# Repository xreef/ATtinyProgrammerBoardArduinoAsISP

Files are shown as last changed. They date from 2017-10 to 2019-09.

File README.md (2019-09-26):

### Additional information and document update here on my site: [ATtyny Article](https://www.mischianti.org/2019/08/02/attiny-programmer-board-arduinouno-as-isp/).

# ATtiny programmer board (ArduinoUNO as ISP) #

Video of Attiny board (https://www.youtube.com/watch?v=rCrS0gHoqbE)

### ATtiny13/ATtiny13a/ATtiny25/ATtiny45/ATtiny85 ###
I really like the ATtiny, and for programmaer It, so I build a simple board to use ArduinoUNO as ISP in a faster way.

For Original ArduinoUNO there is a little variant because compatible one have another 5v VCC over RESET pin,  
Arduino uno have IOREF instead.

(In project you can find fritzing file, the simple examples and schema).

## ATtiny13a variant
I buy ATtiny13a very low cost IC (less than 0.5€), with 4 analog pin and 2 PWM/TIMER PIN. 

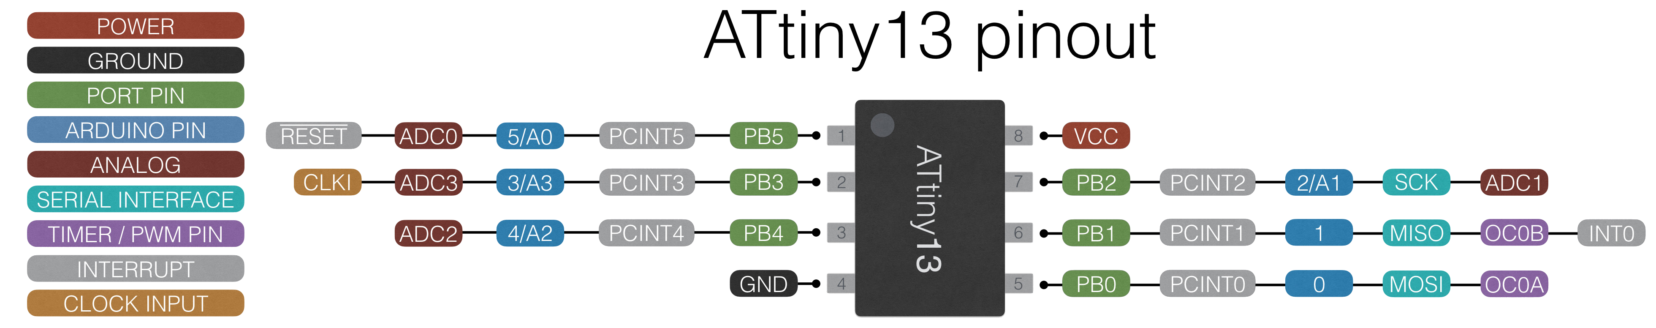
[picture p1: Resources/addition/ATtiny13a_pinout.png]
ATtiny13a pinout


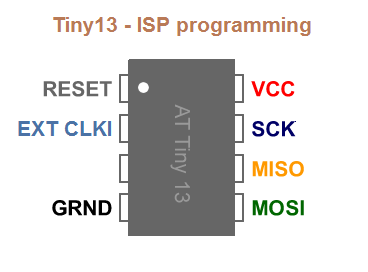
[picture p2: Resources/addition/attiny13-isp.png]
ATtiny13a isp


## How to program an ATtiny:
### Prepare ArduinoUNO to use it as ISP
1. In Arduino IDE select ArduinoUNO board (`Tool --> Board --> ArduinoUNO` - `Strumenti --> Scheda --> ArduinoUNO`);
2. Than open ArduinoISP example file (`File --> Examples/Esempi --> 11.ArduinoISP --> ArduinoISP`);
3. Upload Arduino (`Sketch --> Upload/Carica`);
4. Close IDE.
### Add support for ATtiny:
**ATtiny13/ATtiny13a** ([GitHub ATtiny13 support](https://github.com/MCUdude/MicroCore)):

1. Open the Arduino IDE;
2. Open the `File > Preferences` menu item;
3. Enter the following URL in Additional Boards Manager URLs: [`https://mcudude.github.io/MicroCore/package_MCUdude_MicroCore_index.json`](https://mcudude.github.io/MicroCore/package_MCUdude_MicroCore_index.json) ;
4. Open the `Tools > Board > Boards Manager`... menu item;
5. Wait for the platform indexes to finish downloading;
6. Scroll down until you see the MicroCore entry and click on it;
7. Click Install;
8. After installation is complete close the Boards Manager window.

**ATtiny25/ATtiny45/ATtiny85** ([GitHub other ATtiny support](https://github.com/damellis/attiny/))

1. Open the Arduino IDE;
2. Open the File > Preferences menu item;
3. Enter the following URL in Additional Boards Manager URLs: [`https://raw.githubusercontent.com/damellis/attiny/ide-1.6.x-boards-manager/package_damellis_attiny_index.json`](https://raw.githubusercontent.com/damellis/attiny/ide-1.6.x-boards-manager/package_damellis_attiny_index.json) ;
4. Open the Tools > Board > Boards Manager... menu item;
5. Wait for the platform indexes to finish downloading;
6. Scroll down until you see the MicroCore entry and click on it;
7. Click Install;
8. After installation is complete close the Boards Manager window.

### Upload to ATtiny
1. Attach board to ArduinoUNO;
2. Insert ATtinyXX;
3. If the board is v03 than activate test led otherwise using a breadboard and take VCC from upper right pin of attiny and GND to down left pin, than connect 0 pin (down right) to a led;
4. Select board with correct setting and PORT (`Tools --> Board/Strumenti --> Scheda`);
5. Select Arduino as ISP (`Tools --> Programmer --> Arduino as ISP/Strumenti --> Programmatore --> Arduino as ISP`); 
`note: Arduino as ISP is different from ArduinoISP`.
6. Upload program (`Sketch --> Upload from programmer` / `Schetch --> Carica tramite un programmatore`).
   
### Sample sketch
```cpp
#define PIN 0

void setup()
{
  pinMode(PIN, OUTPUT);
}

void loop()
{
  digitalWrite(PIN, LOW);
  delay(500);
  digitalWrite(PIN, HIGH);
  delay(500);
}

```
   
## Schema:

I use a [prefored board](https://www.aliexpress.com/item/10pcs-lot-3cm-x-7cm-Double-Side-prototype-pcb-3-7-Proto-Board/32685891618.html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,searchweb201602_3_10152_10065_10151_10344_10068_10345_10342_10343_10340_10341_10541_10084_10083_10304_10307_10177_5640015_5590015_10302_10060_10155_10154_10056_10055_10539_10538_5370015_10537_10312_10536_10059_10313_10184_10314_10534_10533_100031_10103_10073_10102_10142_10107,searchweb201603_30,ppcSwitch_2&btsid=0fc181c5-3d4e-4580-bf8d-0318e539854f&algo_expid=0158e307-1a76-404c-8a83-54b0cd5e7954-0&algo_pvid=0158e307-1a76-404c-8a83-54b0cd5e7954), and to switch Voltage and to enable test led I use a smd on/off button instead pin with jumper.

The board is double side so I can attach pin and componend up and down the board. 

Board v01:

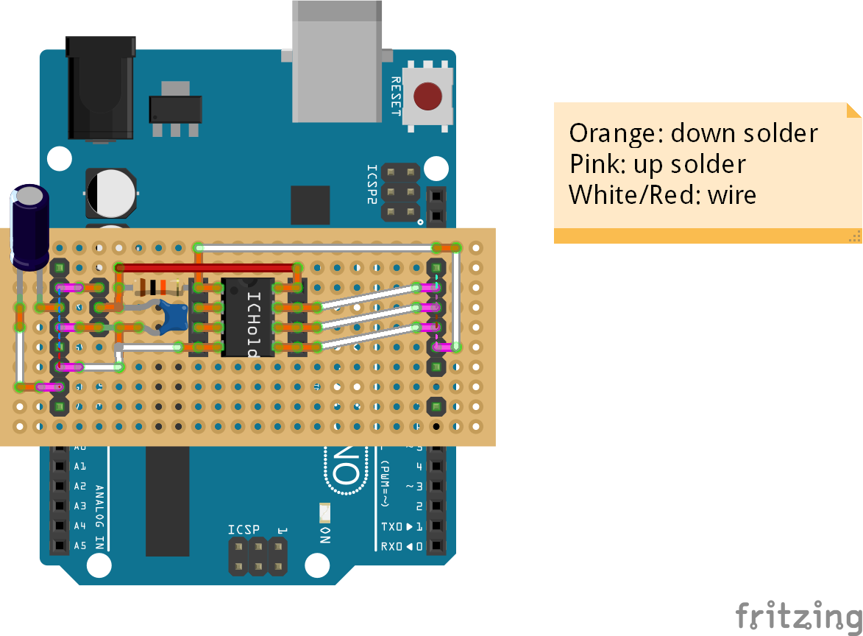
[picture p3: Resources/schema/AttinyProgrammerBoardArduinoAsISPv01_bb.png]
board v01


Board v01 (Original ArduinoUNO):

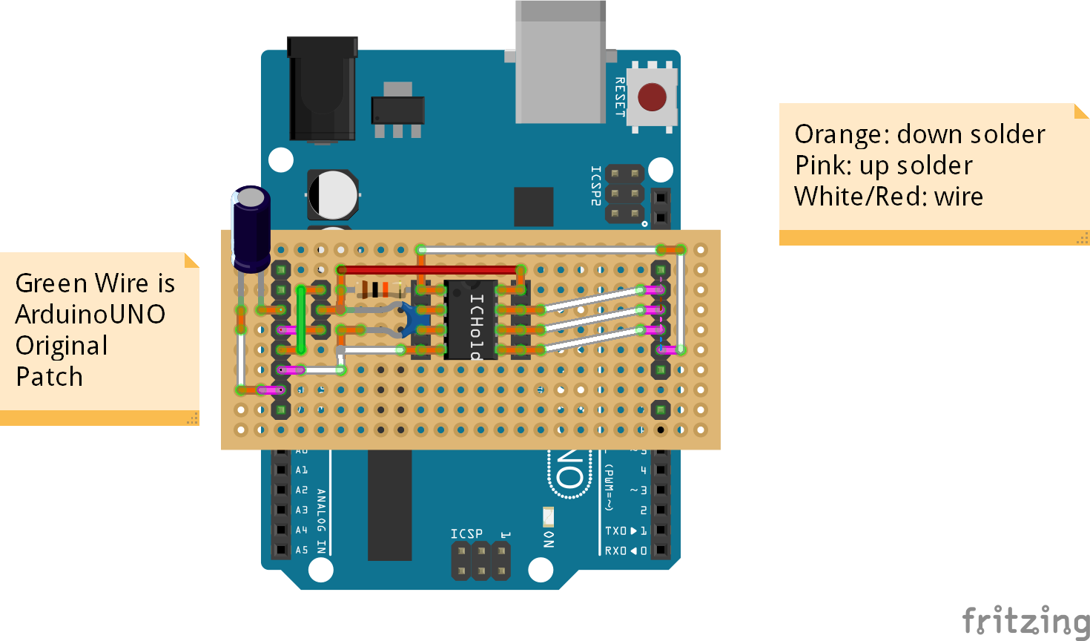
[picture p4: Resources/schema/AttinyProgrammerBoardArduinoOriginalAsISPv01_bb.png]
board v01


Board v02 (power led):

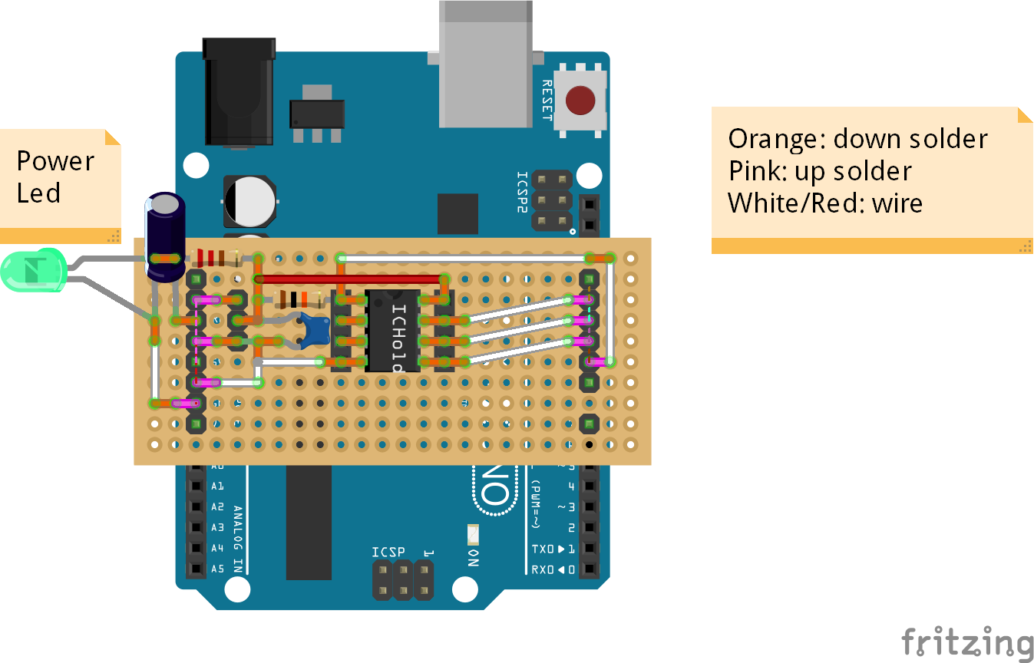
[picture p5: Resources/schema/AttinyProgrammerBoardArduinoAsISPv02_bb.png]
board v02


Board v03 (test led):

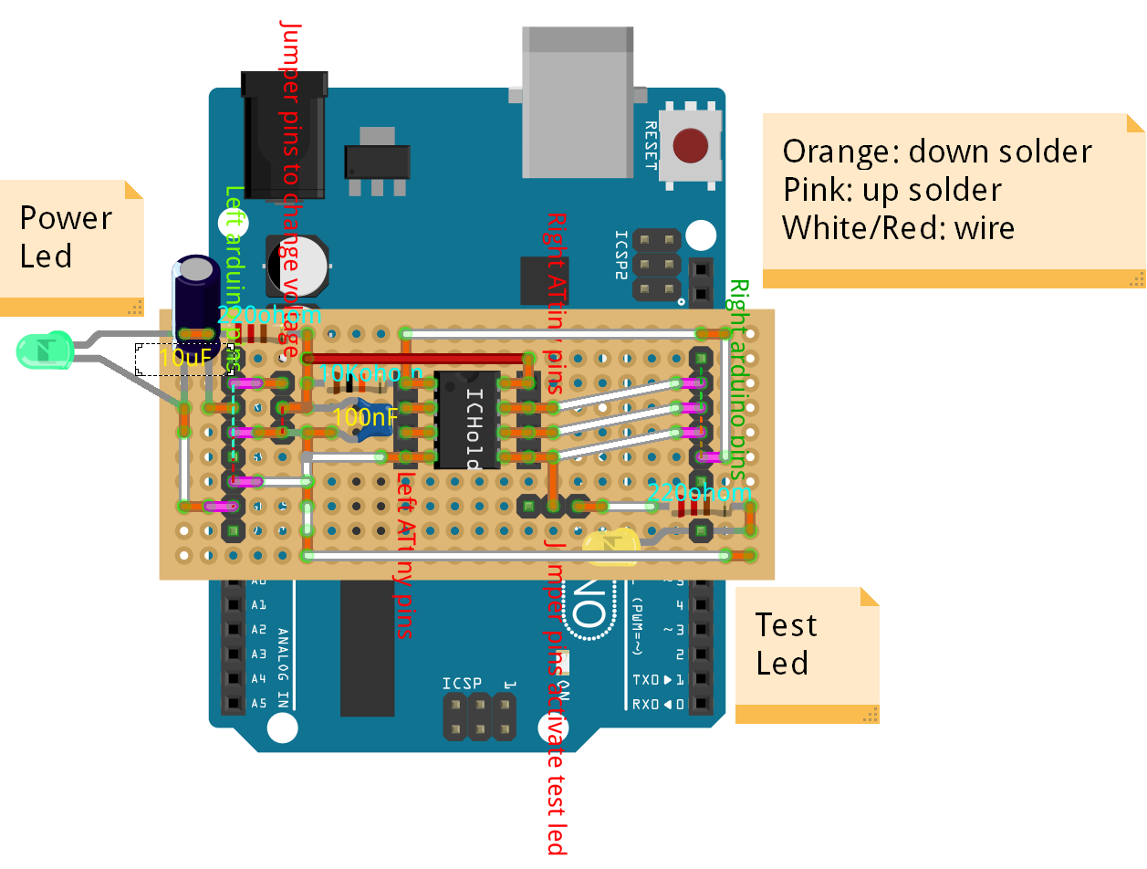
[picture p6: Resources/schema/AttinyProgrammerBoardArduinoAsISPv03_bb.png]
board v03


Schema v03 (test led):

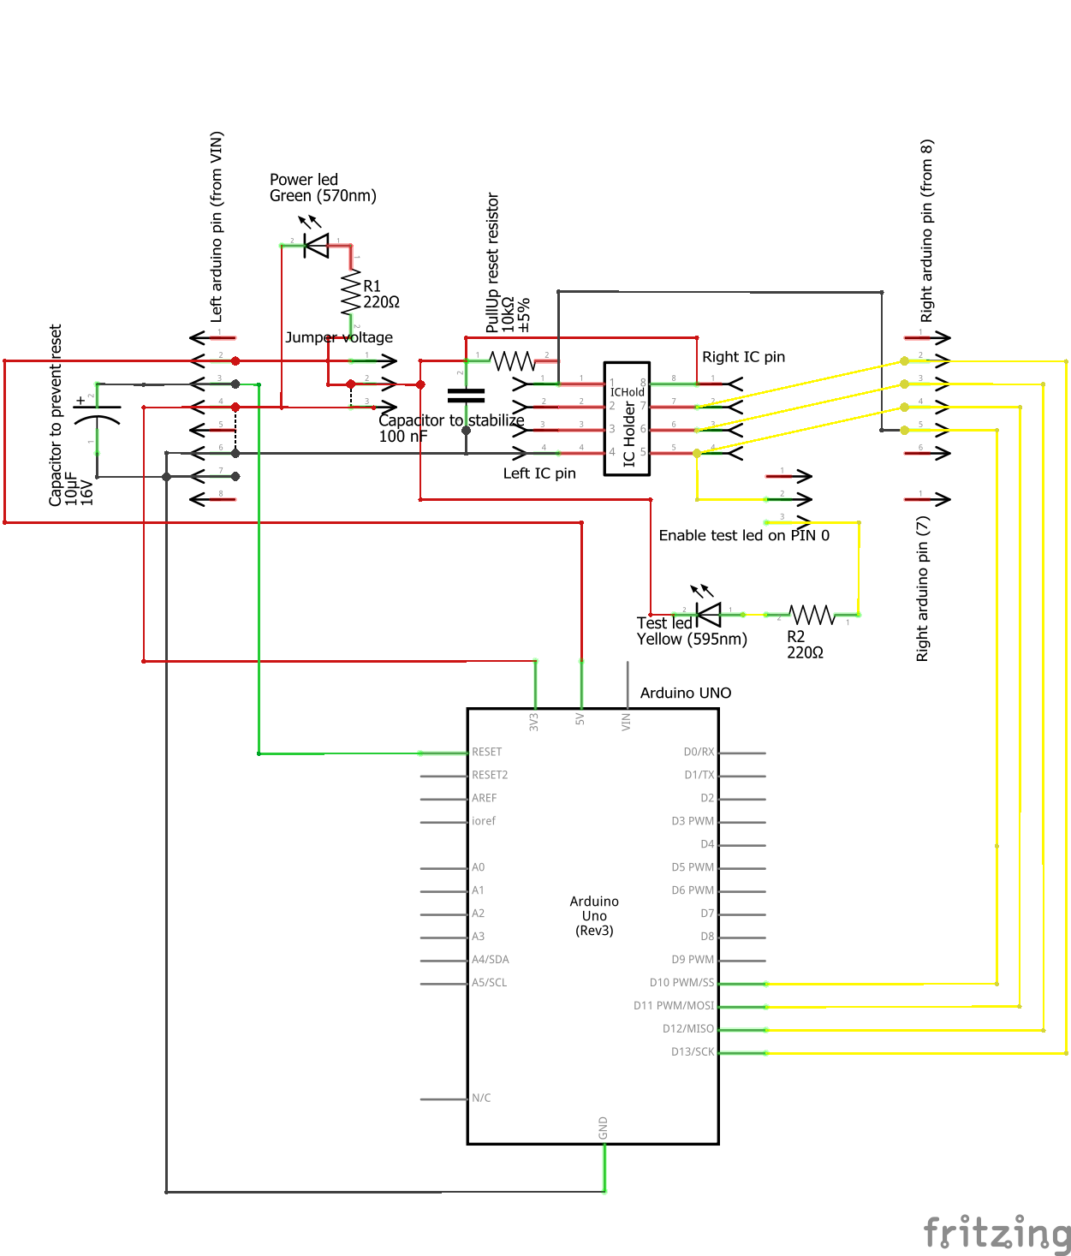
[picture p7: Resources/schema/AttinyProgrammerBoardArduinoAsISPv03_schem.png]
Schema v03


## Material

## Assembly List

| Label | Part Type | Properties |
| --- | --- | --- |
| Arduino UNO | Arduino Uno (Rev3) | tipo Arduino UNO (Rev3) |
| Capacitor to prevent reset | Electrolytic Capacitor | capacitance 10µF |
| Capacitor to stabilize | Ceramic Capacitor | capacitance 100 nF |
| IC Holder | ICHold | pin spacing 300mil; pins 8 |
| Power led | Green (570nm) LED | package 3 mm [THT]; colore Green (570nm); leg yes |
| Test led | Yellow (595nm) LED | package 3 mm [THT]; colore Yellow (595nm); leg yes |
| Left arduino pin (from VIN) | Generic male header - 8 pins | package THT; form ♂ (male); hole size 1.0mm,0.508mm; pin spacing 0.1in (2.54mm); pins 8; row single |
| Left IC pin | Generic female header - 4 pins | package THT; form ♀ (female); hole size 1.0mm,0.508mm; pin spacing 0.1in (2.54mm); pins 4; row single |
| PullUp reset resistor | 10kΩ Resistor | package 2512 [SMD]; resistenza 10kΩ; tolerance ±5% |
| R1 | 220Ω Resistor | bands 4; package THT; resistenza 220Ω; pin spacing 400 mil; tolerance ±5% |
| R2 | 220Ω Resistor | bands 4; package THT; resistenza 220Ω; pin spacing 400 mil; tolerance ±5% |
| Right arduino pin (7) | Generic male header - 1 pins | package THT; form ♂ (male); hole size 1.0mm,0.508mm; pin spacing 0.1in (2.54mm); pins 1; row single |
| Right arduino pin (from 8) | Generic male header - 6 pins | package THT; form ♂ (male); hole size 1.0mm,0.508mm; pin spacing 0.1in (2.54mm); pins 6; row single |
| Right IC pin | Generic female header - 4 pins | package THT; form ♀ (female); hole size 1.0mm,0.508mm; pin spacing 0.1in (2.54mm); pins 4; row single |
| Jumper voltage setting | Generic male header - 3 pins | package THT; form ♂ (male); hole size 1.0mm,0.508mm; pin spacing 0.1in (2.54mm); pins 3; row single |
| Enable test led on PIN0  | Generic male header - 3 pins | package THT; form ♂ (male); hole size 1.0mm,0.508mm; pin spacing 0.1in (2.54mm); pins 3; row single |

## Shopping List

| Amount | Part Type | Properties |
| --- | --- | --- |
| 1 | Arduino Uno (Rev3) | tipo Arduino UNO (Rev3) |
| 1 | Electrolytic Capacitor | capacitance 10µF |
| 1 | Ceramic Capacitor | capacitance 100 nF |
| 1 | IC Holder | pin spacing 300mil; pins 8 |
| 1 | Green (570nm) LED | package 3 mm [THT]; colore Green (570nm); leg yes |
| 1 | Yellow (595nm) LED | package 3 mm [THT]; colore Yellow (595nm); leg yes |
| 1 | 10kΩ Resistor | package 2512 [SMD]; resistenza 10kΩ; tolerance ±5% |
| 2 | 220Ω Resistor | bands 4; package THT; resistenza 220Ω; pin spacing 400 mil; tolerance ±5% |
|  | Generic male header | package THT; form ♂ (male); hole size 1.0mm,0.508mm; pin spacing 0.1in (2.54mm); pins 8; row single |
|  | Generic female header | package THT; form ♀ (female); hole size 1.0mm,0.508mm; pin spacing 0.1in (2.54mm); pins 4; row single |

**ATtiny13a** [I used this for test](https://www.aliexpress.com/item/5Pcs-lot-ATTINY13A-PU-ATTINY13A-ATMEL-ATTINY13-13A-PU-IC-Free-shipping/2041732789.html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,searchweb201602_3_10152_10065_10151_10344_10068_10345_10342_10343_10340_10341_10541_10540_10084_10083_5370020_10304_10307_10177_10302_10060_10155_10154_10056_10055_10539_10538_10537_10312_10536_10059_10313_10184_10314_10534_10533_100031_10103_10073_10102_5590020_5640020_10142_10107,searchweb201603_30,ppcSwitch_2&btsid=271e5ab3-b1d0-4fc8-b0ce-b7d60e4ec24a&algo_expid=40a91871-0e14-4bd1-99fd-60b9e24f5f29-36&algo_pvid=40a91871-0e14-4bd1-99fd-60b9e24f5f29)

## Screen

Preforated board up:

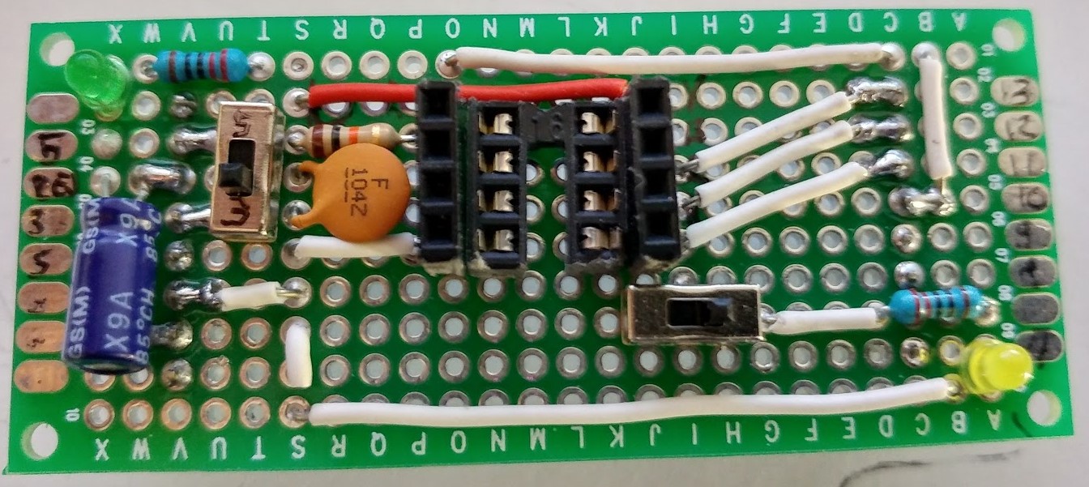
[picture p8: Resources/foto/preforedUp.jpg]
preforated up


Preforated board down:

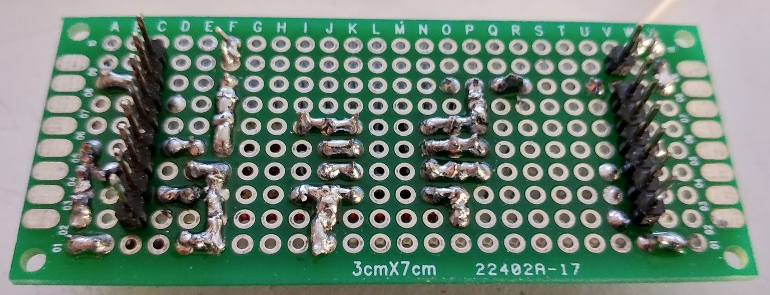
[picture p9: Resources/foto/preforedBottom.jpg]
preforated down


Mount on Arduino:

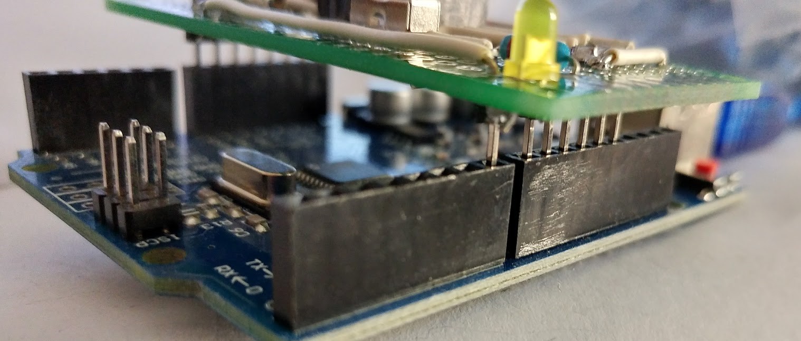
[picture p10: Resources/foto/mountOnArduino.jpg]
Mount on Arduino


After upload:

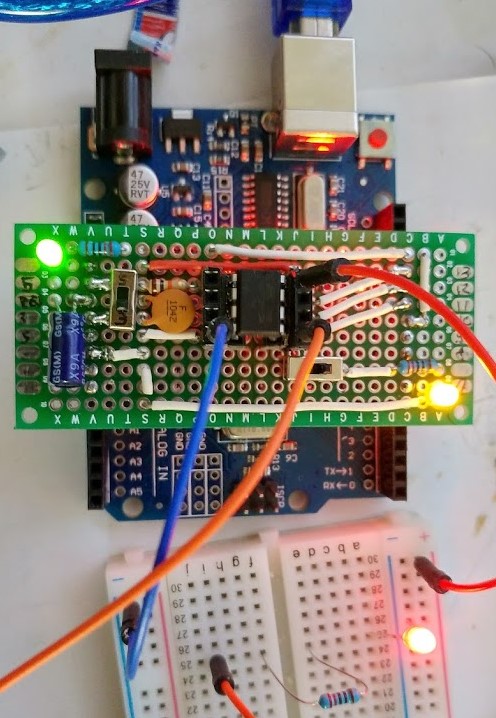
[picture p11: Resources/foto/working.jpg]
After upload


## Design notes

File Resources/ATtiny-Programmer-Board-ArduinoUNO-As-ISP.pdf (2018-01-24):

instructables

## ATtiny Programmer Board (ArduinoUNO As ISP)

by xxreef

ATtiny13/ATtiny13a/ATtiny25/ATtiny45/ATtiny85

I really like the ATtiny and programming it, so I built a simple board to use Arduino UNO as ISP in a faster way.

With the original Arduino UNO, there is a little variant because compatible one have another 5v VCC over RESET pin, Arduino UNO has IOREF instead, but don't worry look at the schema to make the simple change.

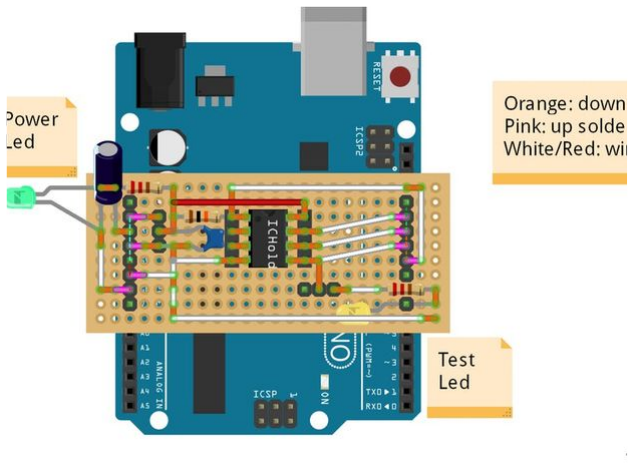
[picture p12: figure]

### Step 1: Schema

In github project you can find the fritzing file with simple examples and schema.

ATtiny Programmer Board (ArduinoUNO As ISP): Page 1

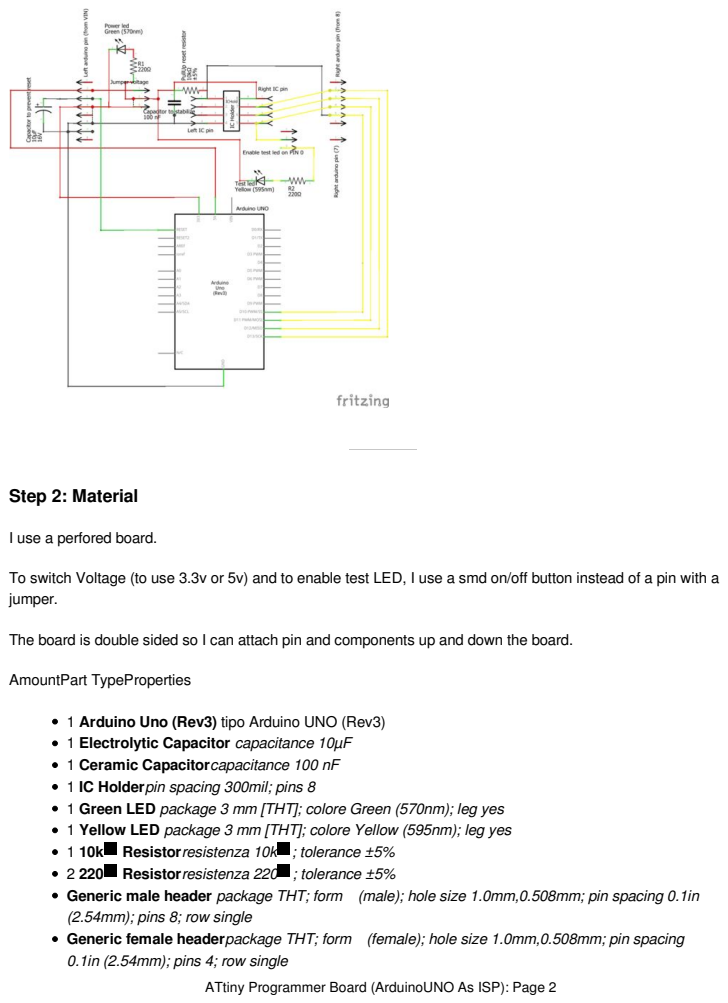
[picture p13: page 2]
Step 2: Material; AmountPart TypeProperties; Resistorresistenza 10k; ; tolerance ±5%; Resistorresistenza 220

I use a perfored board.

To switch Voltage (to use 3.3v or 5v) and to enable test LED, I use a smd on/off button instead of a pin with a
jumper.

The board is double sided so I can attach pin and components up and down the board.

1 Arduino Uno (Rev3) tipo Arduino UNO (Rev3)
1 Electrolytic Capacitor capacitance 10µF
1 Ceramic Capacitorcapacitance 100 nF
1 IC Holderpin spacing 300mil; pins 8
1 Green LED package 3 mm [THT]; colore Green (570nm); leg yes
1 Yellow LED package 3 mm [THT]; colore Yellow (595nm); leg yes
Generic male header package THT; form (male); hole size 1.0mm,0.508mm; pin spacing 0.1in
(2.54mm); pins 8; row single
Generic female headerpackage THT; form (female); hole size 1.0mm,0.508mm; pin spacing
0.1in (2.54mm); pins 4; row single

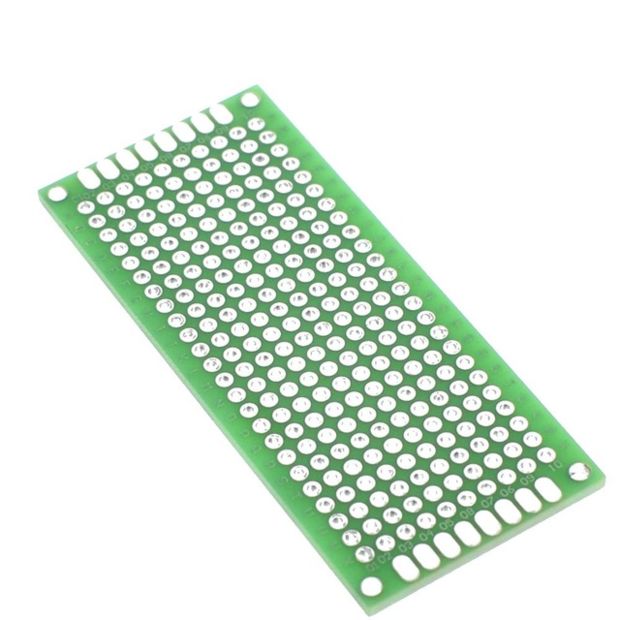
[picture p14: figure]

### Step 3: ATtiny13a Variant

I buy ATtiny13a very low cost IC (less than 0.5€), with 4 analog pin and 2 PWM/TIMER PIN.

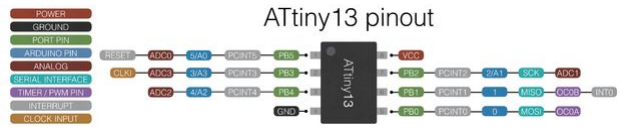
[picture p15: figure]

### Step 4: Board V01

First version of board with no led indicators.

This version work only with fake Arduino.

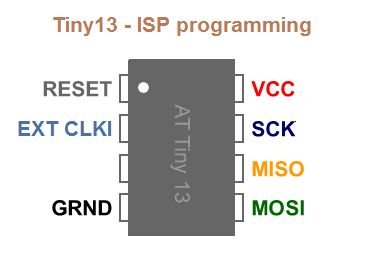
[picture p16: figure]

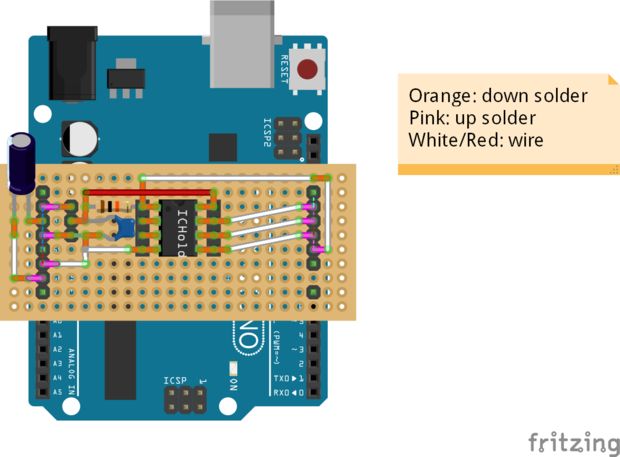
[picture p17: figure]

### Step 5: Board V01 (Original ArduinoUNO)

As you can see for Original Arduino uno you must add a wire to give 5v voltage to switch.

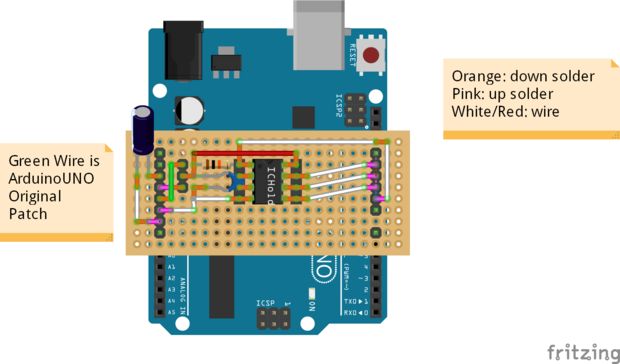
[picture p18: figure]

### Step 6: Board V02 (power Led)

Add green led to control if board have power supply.

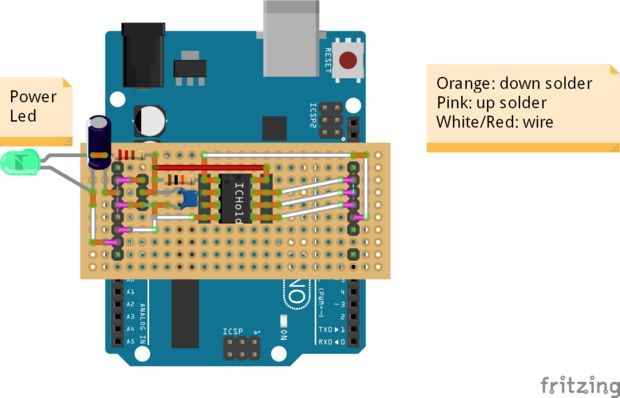
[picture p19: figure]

### Step 7: Board V03 (test Led)

I add a very usefully test led, to check if all is connected correctly.

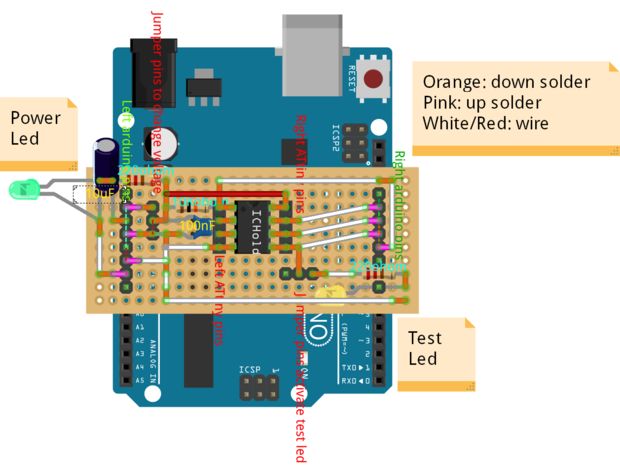
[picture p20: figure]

### Step 8: Board: Voltage Jumper

ATtiny can work at various voltage so I insert a jumper to select ATtiny operating voltage 3v or 5v power supply.

Picture of Board: Voltage Jumper

### Step 9: Board: Test Led Jumper

To test if It's all ok on board I add a test led that can be activated by that jumper.

Picture of Board: Test Led Jumper

### Step 10: Board: Reset Capacitor

To prevent reset when upload code It's important to add a capacitor to reset pin of Arduino.

### Step 11: Board: Voltage Capacitor and Reset Resistor

Other important think is the capacitor to stabilize the voltage and pullup resistor to reset pin of ATtiny.

### Step 12: Assembled Board

The realization is quite simple and the result is very usefully.

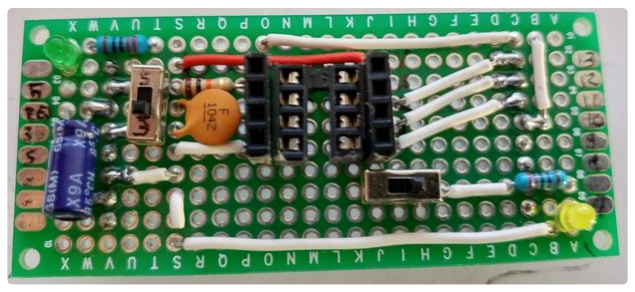
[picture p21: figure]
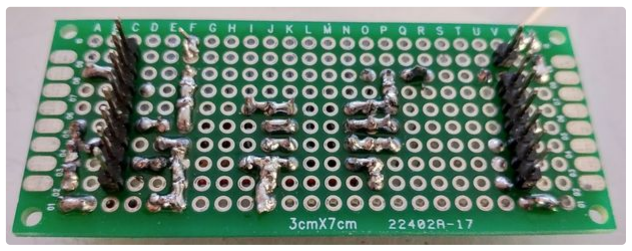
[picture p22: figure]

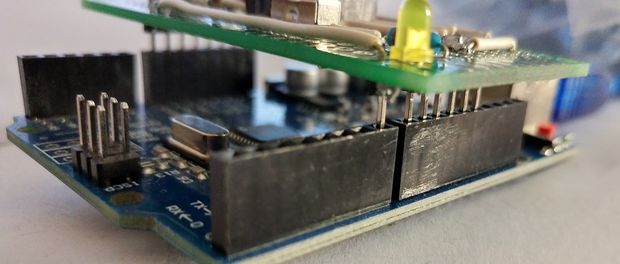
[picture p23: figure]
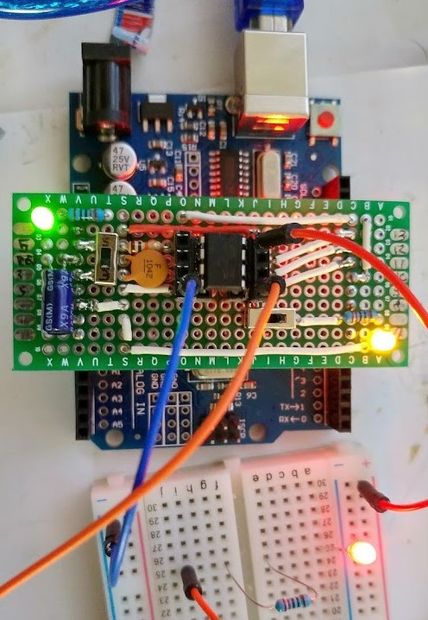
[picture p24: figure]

### Step 13: How to Program an ATtiny: Prepare ArduinoUNO to Use It As ISP

1. In Arduino IDE select ArduinoUNO board (Tool --> Board --> ArduinoUNO - Strumenti --> Scheda --> ArduinoUNO);
2. Than open ArduinoISP example file (File --> Examples/Esempi --> 11.ArduinoISP --> ArduinoISP);
3. Upload Arduino (Sketch --> Upload/Carica);
4. Close IDE.

### Step 14: Add Support for ATtiny: ATtiny13/ATtiny13a

GitHub ATtiny13 support

1. Open the Arduino IDE;
2. Open the File > Preferences menu item;
3. Enter the following URL in Additional Boards Manager URLs: https://mcudude.github.io/MicroCore/package_MCUdu... ;
4. Open the Tools > Board > Boards Manager... menu item;
5. Wait for the platform indexes to finish downloading;
6. Scroll down until you see the MicroCore entry and click on it;
7. Click Install;
8. After installation is complete close the Boards Manager window.

### Step 15: Add Support for ATtiny: ATtiny25/ATtiny45/ATtiny85

GitHub other ATtiny support

1. Open the Arduino IDE;
2. Open the File > Preferences menu item;
3. Enter the following URL in Additional Boards Manager URLs: https://raw.githubusercontent.com/damellis/attiny... ;
4. Open the Tools > Board > Boards Manager... menu item;
5. Wait for the platform indexes to finish downloading;
6. Scroll down until you see the MicroCore entry and click on it;
7. Click Install;
8. After installation is complete close the Boards Manager window.

### Step 16: How to Program an ATtiny: Upload to ATtiny

1. Attach board to ArduinoUNO;
2. Insert ATtinyXX;
3. If the board is v03 than activate test led otherwise using a breadboard and take VCC from upper right pin of attiny and GND to down left pin, than connect 0 pin (down right) to a led;
4. Select board with correct setting and PORT (Tools --> Board/Strumenti --> Scheda);
5. Select Arduino as ISP (Tools --> Programmer --> Arduino as ISP/Strumenti --> Programmatore --> Arduino as ISP);note: Arduino as ISP is different from ArduinoISP.
6. Upload program (Sketch --> Upload from programmer / Schetch --> Carica tramite un programmatore).

### Step 17: Sample Sketch

A simple scketch to upload to ATtiny

#define PIN 0

void setup()
{
pinMode(PIN, OUTPUT);
}

void loop()
{
digitalWrite(PIN, LOW);
delay(500);
digitalWrite(PIN, HIGH);
delay(500);
}

### Step 18: Thanks

In github project you can find some additional info and schema.

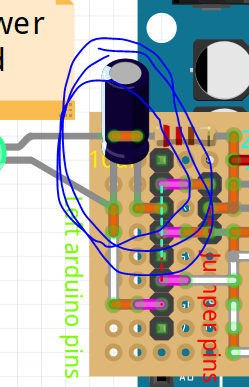
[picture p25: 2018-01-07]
Resources/schema/capacitorPreventReset.PNG

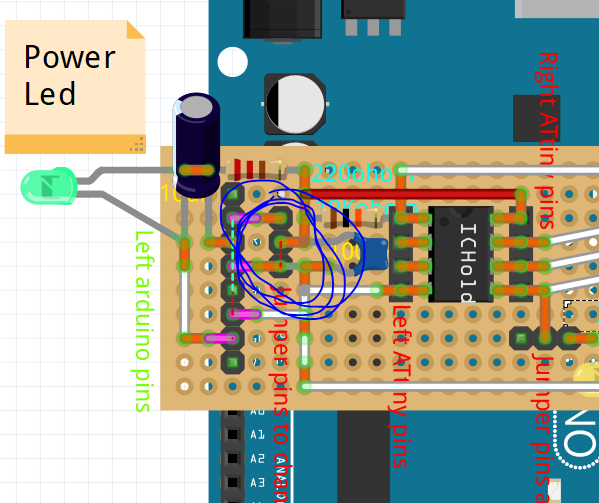
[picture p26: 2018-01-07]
Resources/schema/jumper.PNG

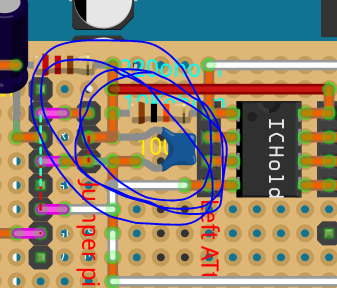
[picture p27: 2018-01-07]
Resources/schema/capacitorAndResetResistor.PNG

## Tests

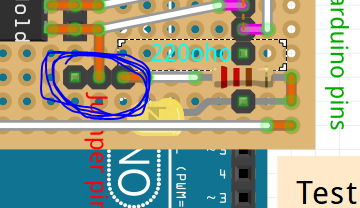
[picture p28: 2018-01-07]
Resources/schema/jumperTestLed.PNG

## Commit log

2017-11-15 Readme and schema fix
    [AttinyProgrammerBoardArduinoAsISPv03.fzz]
2017-12-14 Minor PCB fix
    [AttinyProgrammerBoardArduinoAsISPv03.fzz]
2017-12-15 Minor fix
    [AttinyProgrammerBoardArduinoAsISPv03.fzz]
